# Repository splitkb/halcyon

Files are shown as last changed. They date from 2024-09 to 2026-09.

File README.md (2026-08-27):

# Halcyon Series

The Halcyon Series is a series of pre-built (split) keyboard kits made by [splitkb.com](https://splitkb.com/kits). In this repository you'll find files you can use to make your own case for these keyboards.

THE SOFTWARE IS PROVIDED "AS IS", WITHOUT WARRANTY OF ANY KIND, EXPRESS OR IMPLIED, INCLUDING BUT NOT LIMITED TO THE WARRANTIES OF MERCHANTABILITY, FITNESS FOR A PARTICULAR PURPOSE AND NONINFRINGEMENT. IN NO EVENT SHALL THE AUTHORS OR COPYRIGHT HOLDERS BE LIABLE FOR ANY CLAIM, DAMAGES OR OTHER LIABILITY, WHETHER IN AN ACTION OF CONTRACT, TORT OR OTHERWISE, ARISING FROM, OUT OF OR IN CONNECTION WITH THE SOFTWARE OR THE USE OR OTHER DEALINGS IN THE SOFTWARE.

These files are available for non-commercial use only. You explicitly have permission to make objects with these files for yourself, friends, family and coworkers. If you'd like to sell objects made from these files, please [get in touch](mailto:support@splitkb.com?subject=Halcyon%20case%20licensing).

## Supported keyboards

You'll find folders in this repository, where each keyboard gets its own folder. Does your keyboard not have a folder yet? Then we're working on adding the files still. Feel free to [join our Discord server](https://splitkb.com/discord) for status updates and questions.

## Other files

Some folders contain files for accessories and other parts of the Halcyon ecosystem.

### Dongle

The dongle case files are provided as STL files for 3D printing:

dongle-body.stl: the main body of the dongle case.
dongle-lid.stl: the lid for the dongle case.

These files are intended to be 3D printed. You may modify them to suit your printer, materials, or preferred assembly method.

### Halcyon module template

A template for a Halcyon module is also included. Use this template as a reference when designing or modifying your own Halcyon-compatible modules. A README is included in the folder.

## Which files do I need?

1. Look for the folder of your keyboard.
2. Decide whether you need kerf (see below: What's kerf?).
3. Pick the files for your keyboard:
    - **A bottom plate**: We have normal plates and puck plates. A normal plate is a fully covered plate, whereas a puck plate is compatible with the splitkb.com [Tenting Puck](https://splitkb.com/products/tenting-puck). It has a circular slot cut out for the puck to sit into. Bottom plates can easily be replaced later, so feel free to get a normal plate if you don't have a puck yet.
    - **A top plate**: We have normal plates, no puck plates and encoder plates. Normal plates have mounting holes, holes for switches, and holes for the puck screws to be mounted through. I recommend getting the normal plates, as the extra holes don't impact functionality and make it easier to add a puck later. The "no puck" plates don't have these extra mounting holes, and the "encoder" plates have wider holes for when you want to use an encoder on a choc-based build. You'll likely want to modify the encoder files before using them, as an encoder hole is larger and won't allow a switch to clip into the plate.
    - **An OLED cover**: Most keyboards will support OLED covers. They protect the microcontroller and display area. Even if you don't use an OLED, I still recommend using a cover, as it'll make the keyboard look more finished. If your keyboard doesn't have a file with "OLED Cover" in its name, then a cover isn't supported.

All files are symmetrical, meaning you use the same file for both the left and the right side. When ordering parts, make sure you order two of every file you've selected.

The files in this repository are DXF files, which can be opened using a tool like LibreCAD, Adobe Illustrator or other similar CAD or graphic design software packages. You'll be able to send these to a manufacturer to produce cases with for personal use, or modify them using a tool like Fusion 360 to make your own 3D-printable cases.

## What's kerf?

Kerf is the amount of material that's lost in the process of cutting, for example with a laser or water jet. As the cutter moves along the lines in the file, material is removed from either side of the line. Files that account for kerf, add a little bit of material to the edges of all cut lines to compensate for that lost material.

In short, if you're using a laser cutter yourself, you'll want the files with kerf. If you're sending them off to another service, you should ask them whether to include kerf. And if you're 3D printing, you shouldn't need any kerf, or might even need to remove some extra material depending on your printer and calibration.

The files with kerf that we supply are used with our own laser cutter. Third parties might require different settings. We don't supply those files, so you or the third party may have to modify the files to match their process.

## Which thickness do I need?

It depends! Generally:

- For MX switches, 1.5mm is best for the top plate if the material is sturdy enough. For acrylic, go with 3mm.
- For Choc switches, 1.2mm is best for the top plate if the material is sturdy enough. 1.5mm is also fine, and in most cases this makes it compatible with both MX and Choc. For acrylic, go with 3mm and a hand-solderable kit. **Hot swapping 3mm plates makes for a bad experience.**
- For the bottom plate and OLED cover, thickness doesn't matter a lot. We usually go with 3mm for acrylic.

## Which hardware do I need?

The number and lengths of spacers and screws will depend on the keyboard, the switches you use, and the plate thicknesses you choose. You can get all the hardware and some extras when buying an [Aurora Hardware Kit](https://splitkb.com/products/aurora-low-profile-case-hardware-kit).

We also sell various hardware separately:

- [M2 spacers in various lenghts](https://splitkb.com/products/brass-m2-spacers)
- [M2 screws in various lenghts](https://splitkb.com/products/m2-screws)

Generally:

- For MX switches and a metal top plate, go with 8mm spacers.
- For MX switches and an acrylic top plate, go with 6mm spacers.
- For Choc switches and a metal top plate, go with 6mm spacers.
- For Choc switches and an acrylic top plate, go with 4mm spacers.

The OLED cover requires 12mm spacers when using a display, though you might get away with 10mm in some cases. If you don't use a display, you can use 8mm or maybe even 6mm spacers.

## What should I keep in mind?

To prevent disappointment, take care of the following:

- Make sure of some measurements beforehand. For files without kerf, the size of a switch hole will be exactly 14x14mm. For files with kerf, the size of a switch hole will be exactly 13.9x13.9mm.
- Only use plates thicker than 1.6mm with hand solder kits. Hot swapping with thick plates is a bad experience.
- Only use acrylic as a material with plates thicker than 2mm, preferably 3mm. Thin acrylic is fragile and is likely to break during assembly.
- Take care when ordering detoriable materials like copper or brass. They will oxidate over time, which can give a nice patina look when done, but results definitely vary. If you'd like to keep copper or brass nice, take care to wax or coat it, preferably every once in a while.
- When painting or coating plates, some material is added. You might want to enlarge the switch holes to compensate for added thickness paint may add.

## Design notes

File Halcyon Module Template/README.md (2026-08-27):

# Halcyon Module Template

This guide will give you general guidelines on how to design your own Halcyon Modules.

## Designing the schematics

Our modules use the [VIK](https://github.com/sadekbaroudi/vik) standard. However our module design differ a small bit. Because the placement of the VIK connector is on the bottom side on our keyboards we needed to use a type D cable (Opposite side contacts) as the cable folds over. Because of this our module connecter is mirrored in pinout compared to the VIK standard.

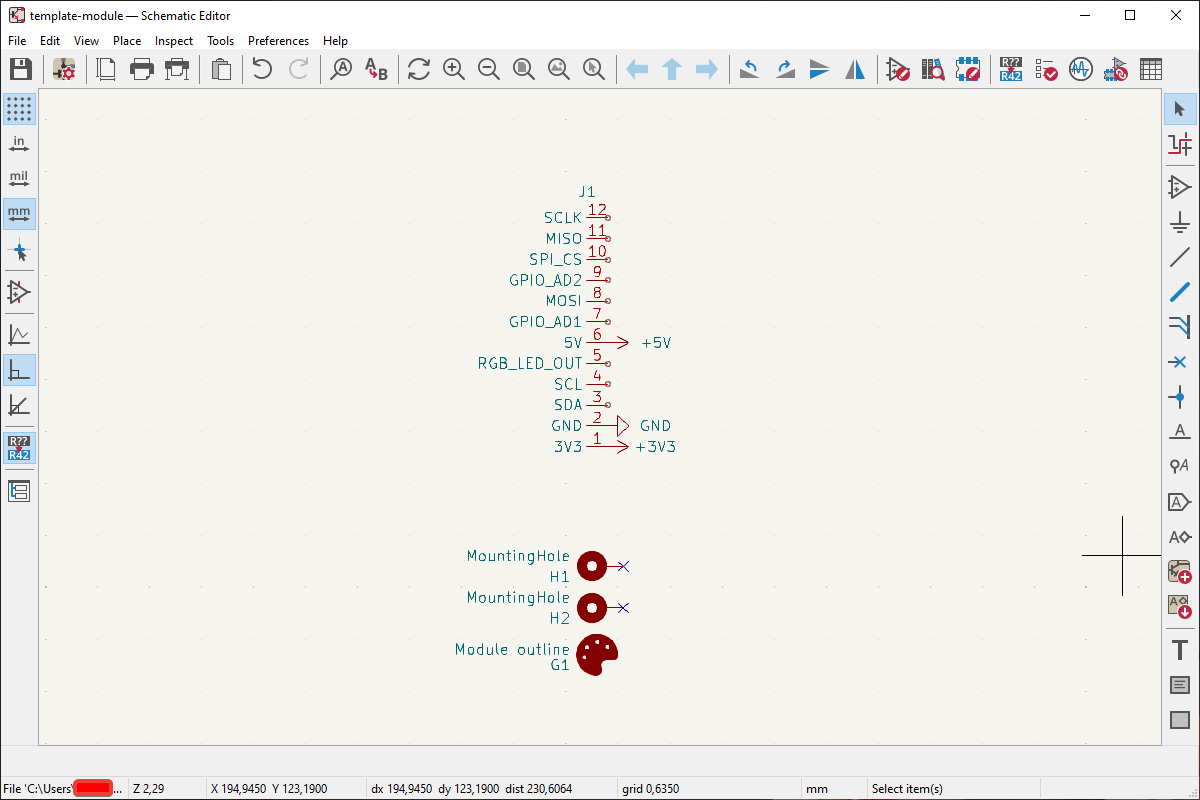
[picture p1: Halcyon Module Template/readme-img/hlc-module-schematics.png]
Halcyon module schematics


## Designing the PCB

You can start out with the KiCad template inside this folder. If you don't use KiCad you can use the [dimensions as shown below](#dimensions).

### Mounting holes 

The template can be simplified by changing out the bottom two standoffs with two M2 holes. You could then use M2 screws and 6mm spacers instead. Similar to the Cirque Trackpad mounting mechanism. But you will loose quite a bit of space on the top of the module from the screw heads. 

### VIK connector

The VIK connector position and part number is mostly a suggestion. But the position is ideal for using a 5cm FPC cable. Any other FPC connector with 12 contacts and a pitch of 0.5mm could also be used. The position and part number is the same as with our own modules. You may notice a small keepout area on the PCB. This is because the FPC cable has a small stiffer part on the ends to help with inserting the cable. But because of this you can not add any components directly under that as the cable will sit quite flush with the PCB itself.

### Clearance

The height of components on the bottom side should not exceed roughly 2.8mm. This is because otherwise they would interfere with the controller. This clearance may change if we ever release any other controllers. So it's best to keep the components on the bottom to a minimum. But any small components like resistors, capacitors or IC's are mostly fine.

## Components

| Reference | Manufacturer Part No. | Description |
|---|---|---|
| H1, H2 | 97730606332R | Standoff Wuerth WA-SMSI M1.6 H6mm Thread Depth 2mm |
| J1 | HC-FPC-05-10-12RLTAG | FPC Connector |

## Dimensions

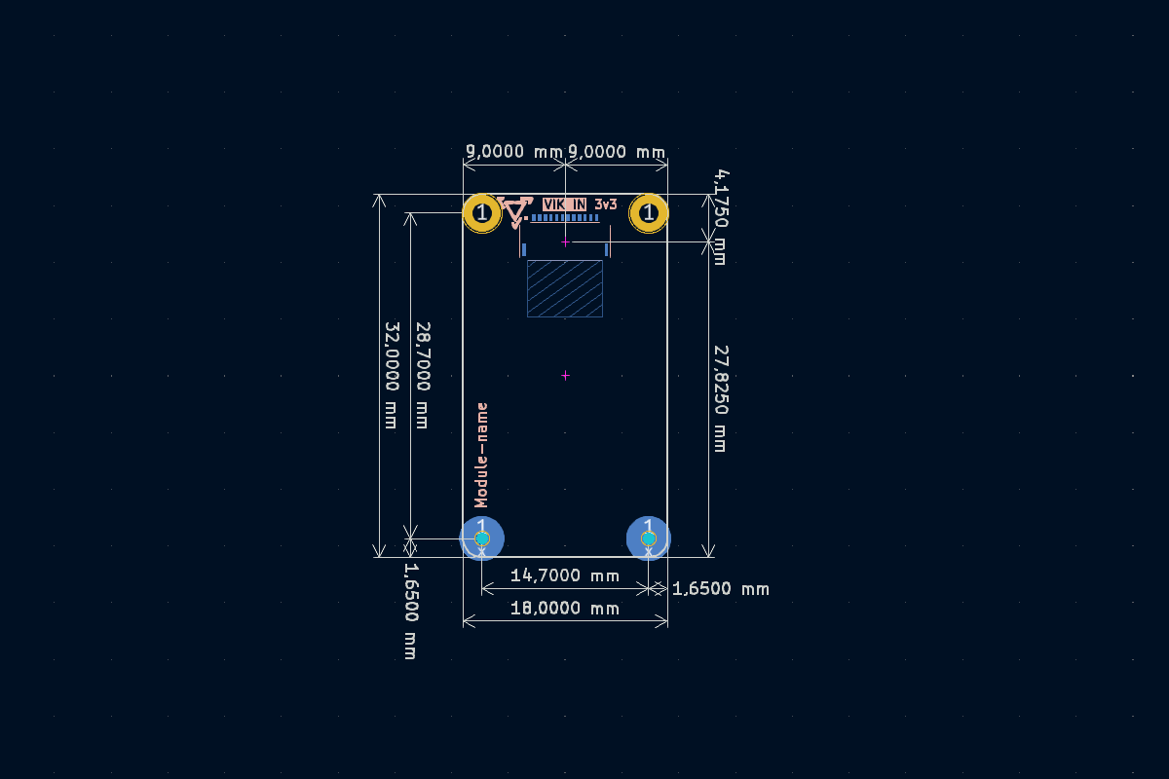
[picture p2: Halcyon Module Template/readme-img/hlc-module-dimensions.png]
Halcyon module dimensions


The mounting holes at the top have an inner diameter of 1.8mm. The pad size is 3.3mm in diameter.

## Making QMK firmware

This will be more of a general overview on how to add a module. As any custom module can be as advanced or simple as you can make it. 

First make sure you have your userspace or firmware setup by following the [compiling firmware guide](https://github.com/splitkb/qmk_userspace). 

Within the `users/halcyon_modules` folder you will notice that each module has it's own folder.

### Pinout

The following pins are connected to the following RP2040 pins.

* SCLK = GP14  
* MISO = GP12  
* MOSI = GP15  
* SPI_CS = GP13  
* SCL = GP17  
* SDA = GP16  
* GPIO1_AD1 = GP27  
* GPIO2_AD2 = GP26  

### Creating the necessary files

A module will usually have the following files:
* A `config.h` file
* `.c` and `.h` file for custom code
* A `rules.mk` file

Create a new folder for your module and give it a name and create both a `rules.mk` and `config.h` file.

Within the new `users/halcyon_modules/splitkb/<module_name>/rules.mk` add the following lines:

```makefile
CURRENT_DIR := $(dir $(realpath $(lastword $(MAKEFILE_LIST))))

CONFIG_H += $(CURRENT_DIR)/config.h
```

If you add any other `.c` file you can also add that here by using `SRC += $(CURRENT_DIR)/<your_custom_c_code>.c` here.

Within the new `users/halcyon_modules/splitkb/<module_name>/config.h` add the following lines:

```c
#pragma once

#define <MODULE_NAME>
```

### Configuration for compiling

Now we want to add this module to the main portion of the code so it can be compiled. Within the `users/halcyon_modules` add the following:

For `users/halcyon_modules/splitkb/halcyon.c`:

Add a new `#ifdef` with your module name:
```c
#ifdef <MODULE_NAME>
    module_t module = <module_name>;
#endif
``` 

For `users/halcyon_modules/splitkb/halcyon.h`:

Add the same <module_name> to the enum list

For `users/halcyon_modules/splitkb/rules.mk`:

Add another `ifdef` here to include the new rules.mk you created earlier. And also add your module to the `HLC_OPTIONS` list at the bottom. You can also update the error accordingly if you want.

```c
ifdef <MODULE_NAME>
  include $(CURRENT_DIR)/<module_name>/rules.mk
endif
```

From here on out, the sky is the limit. Add any custom code or QMK options. Any config.h or rules.mk options from the QMK documentation for the specific module can be added to your `users/halcyon_modules/splitkb/<module_name>` folder.

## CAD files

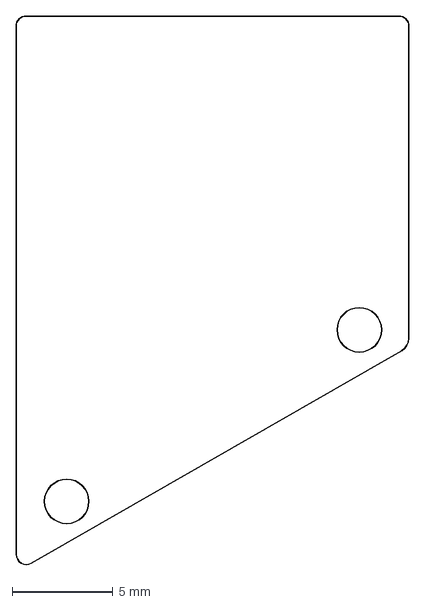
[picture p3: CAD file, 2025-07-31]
Case files/Corne/Halcyon Corne Short OLED Cover - No Kerf.dxf
19.5 x 27.2 mm

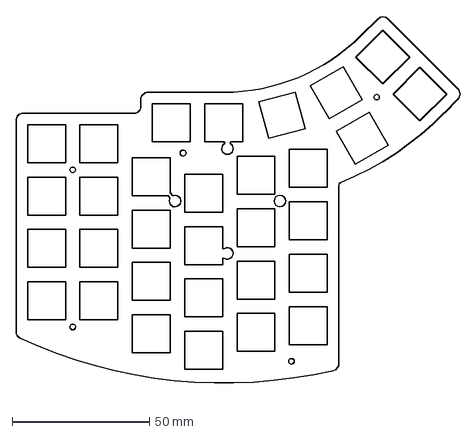
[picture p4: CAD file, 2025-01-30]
Case files/Elora/Elora rev2 Top Plate - 0.1mm Kerf.dxf
161.5 x 137.8 mm

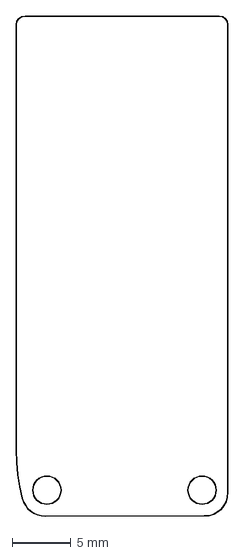
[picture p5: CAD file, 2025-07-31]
Case files/Ferris/Halcyon Ferris OLED Cover - No Kerf.dxf
18.0 x 42.5 mm

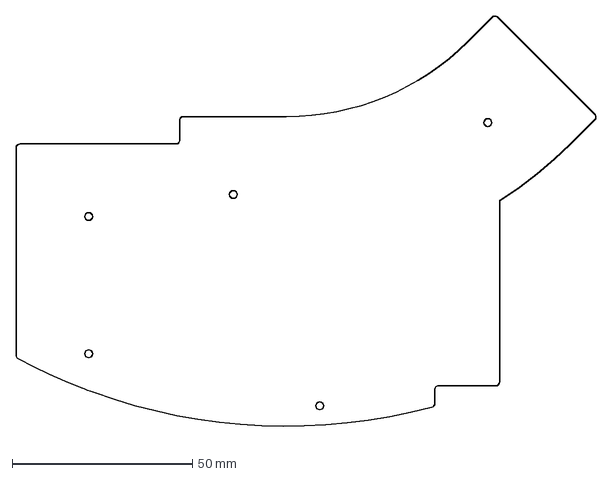
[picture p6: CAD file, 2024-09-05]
Case files/Kyria/Kyria rev4 Bottom Plate - 0.1mm Kerf.dxf
161.0 x 116.8 mm

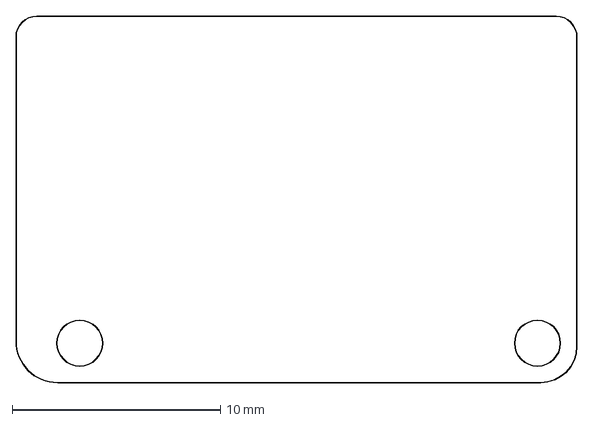
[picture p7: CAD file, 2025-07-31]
Case files/Lily58/Halcyon Lily58 Short OLED Cover - No Kerf.dxf
27.0 x 17.6 mm

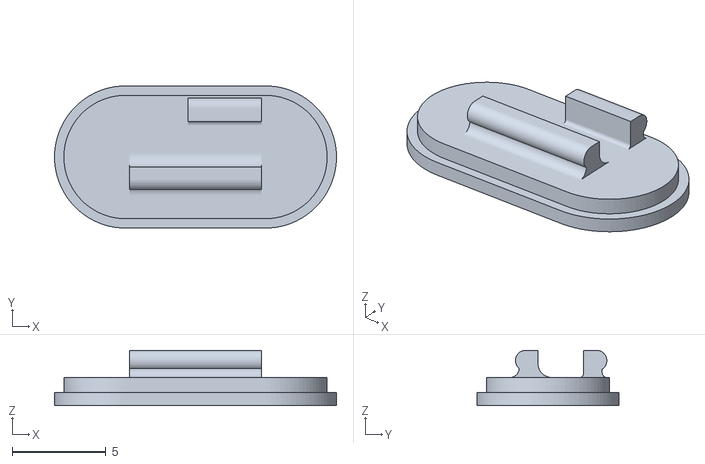
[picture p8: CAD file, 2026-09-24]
Dongle/dongle-lid.stl
15.0 x 7.57 x 2.95

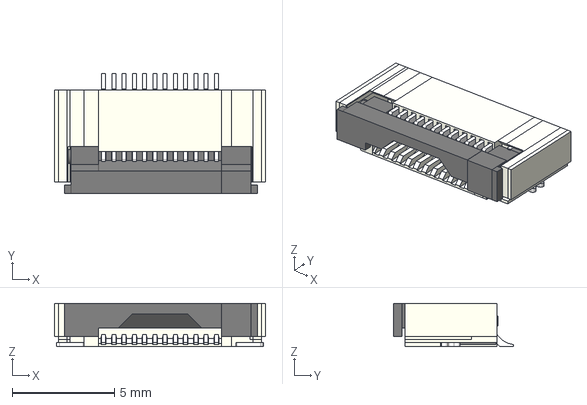
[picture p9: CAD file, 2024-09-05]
Halcyon Module Template/template-module/Footprint Library/3D models/vik-connector-horizontal.stp
10.3 x 5.85 x 2.11 mm

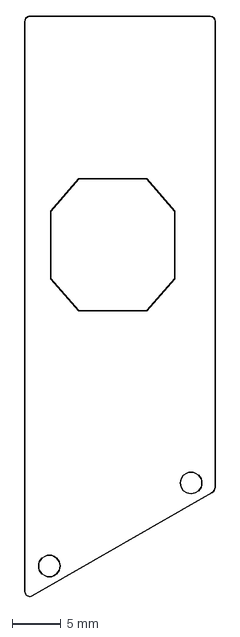
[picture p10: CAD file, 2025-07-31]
Case files/Corne/Halcyon Corne Encoder OLED Cover - No Kerf.dxf
19.5 x 59.4 mm

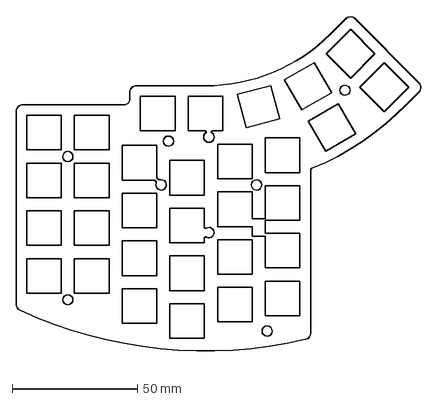
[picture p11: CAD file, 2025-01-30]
Case files/Elora/Elora rev2 Sound plate - 0.1mm Kerf.dxf
161.5 x 137.8 mm

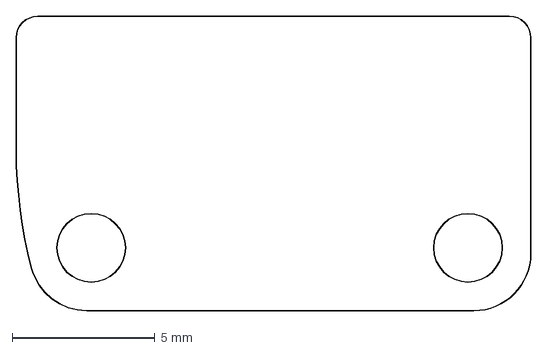
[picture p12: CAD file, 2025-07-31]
Case files/Ferris/Halcyon Ferris Short OLED Cover - No Kerf.dxf
18.0 x 10.3 mm

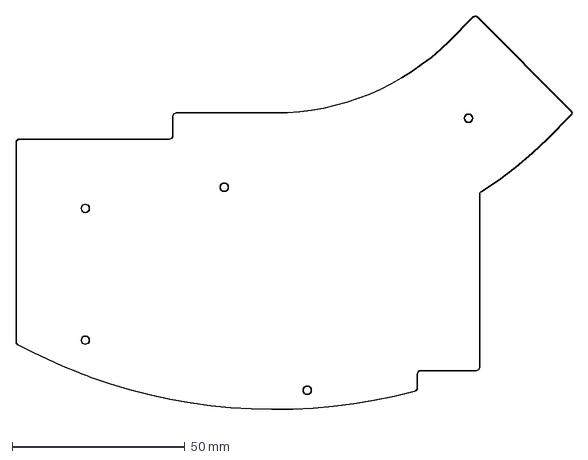
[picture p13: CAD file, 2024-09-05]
Case files/Kyria/Kyria rev4 Bottom Plate - No Kerf.dxf
160.8 x 116.6 mm

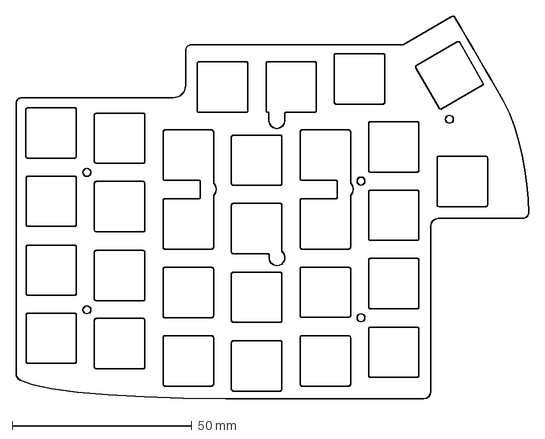
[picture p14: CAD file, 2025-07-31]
Case files/Lily58/Halcyon Lily58 Top Plate - No Kerf.dxf
142.5 x 106.3 mm

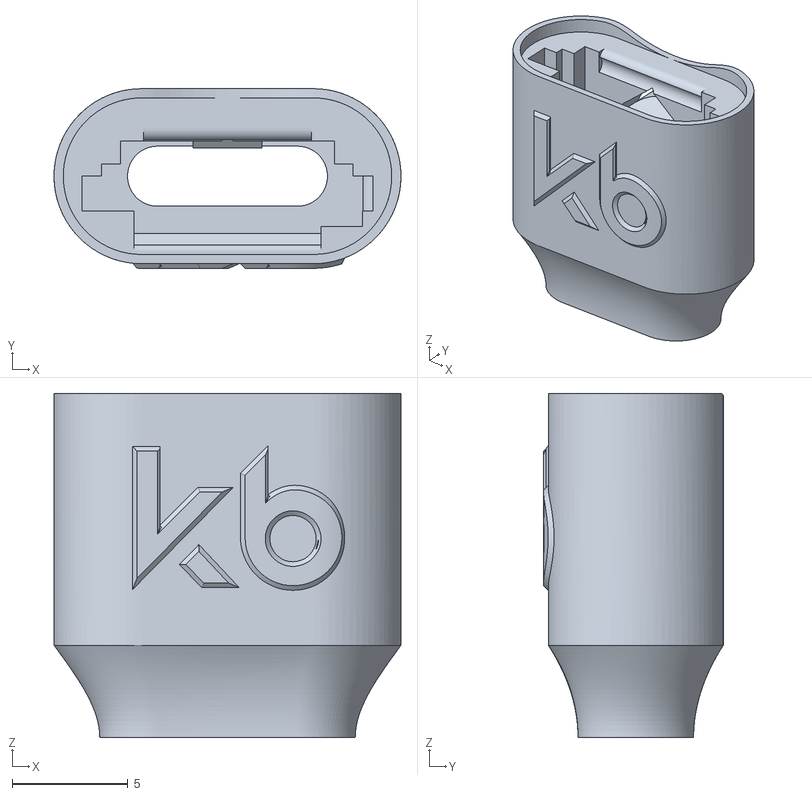
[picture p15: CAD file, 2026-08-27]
Dongle/dongle_body.stl
15.0 x 7.77 x 14.9

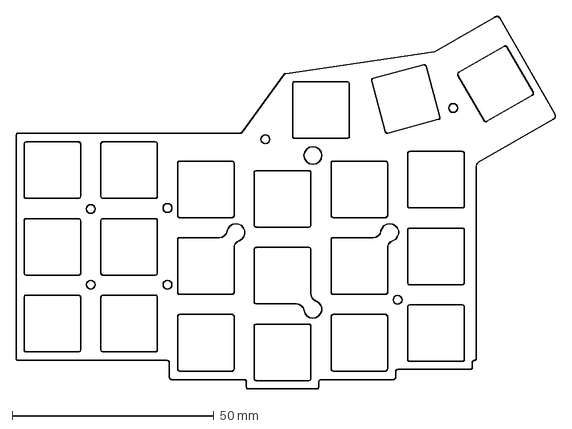
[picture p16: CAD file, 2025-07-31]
Case files/Corne/Halcyon Corne Top Plate - No Kerf.dxf
133.7 x 92.2 mm

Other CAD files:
Case files/Elora/Elora rev2 Bottom Plate - 0.1mm Kerf.dxf
Case files/Ferris/Halcyon Ferris Sound Plate - 0.1mm Kerf.dxf
Case files/Kyria/Kyria rev4 Top Plate - No Puck - 0.1mm Kerf.dxf
Case files/Lily58/Halcyon Lily58 Encoder OLED Cover - 0.1mm Kerf.dxf
Case files/Corne/Halcyon Corne Bottom Plate - 0.1mm kerf.dxf
Case files/Corne/Halcyon Corne Bottom Plate - No kerf.dxf
Case files/Corne/Halcyon Corne Bottom Plate - Puck - 0.1mm Kerf.dxf
Case files/Corne/Halcyon Corne Bottom Plate - Puck - No kerf.dxf
Case files/Corne/Halcyon Corne Cirque Trackpad OLED Cover - 0.1mm Kerf.dxf
Case files/Corne/Halcyon Corne Cirque Trackpad OLED Cover - No Kerf.dxf
Case files/Corne/Halcyon Corne Encoder OLED Cover - 0.1mm Kerf.dxf
Case files/Corne/Halcyon Corne OLED Cover - 0.1mm Kerf.dxf
Case files/Corne/Halcyon Corne OLED Cover - No Kerf.dxf
Case files/Corne/Halcyon Corne Short OLED Cover - 0.1mm Kerf.dxf
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

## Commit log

2024-09-05 add kyria casefiles and module template
    [Kyria rev4 Bottom Plate - 0.1mm Kerf.dxf, Kyria rev4 Bottom Plate - No Kerf.dxf, Kyria rev4 Bottom Plate - Puck - 0.1mm Kerf.dxf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]
2024-09-10 Update template
    [template-module.kicad_sch]
2025-01-30 Add elora case files
    [Elora rev2 Bottom Plate - 0.1mm Kerf.dxf, Elora rev2 Bottom Plate - No Kerf.dxf, Elora rev2 Bottom Plate - Puck - 0.1mm Kerf.dxf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]
2025-07-31 Add Ferris, Corne and lily58 case files
    [Halcyon Corne Bottom Plate - 0.1mm kerf.dxf, Halcyon Corne Bottom Plate - No kerf.dxf, Halcyon Corne Bottom Plate - Puck - 0.1mm Kerf.dxf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]
2026-08-27 Add Dongle case files and move template readme to github
    [dongle-lid.stl, dongle_body.stl, template-module.kicad_pcb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]
2026-09-24 Update dongle lid file
    [dongle-lid.stl]
